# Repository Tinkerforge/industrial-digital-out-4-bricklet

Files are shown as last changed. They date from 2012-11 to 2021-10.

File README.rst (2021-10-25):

Industrial Digital Out 4 Bricklet
=================================

This repository contains the firmware source code and the hardware design
files. The documentation generator configs can be found at
https://github.com/Tinkerforge/generators

Repository Content
------------------

software/:
 * examples/: Examples for all supported languages
 * build/: Compiled files
 * src/: Source code of firmware
 * Makefile: Makefile to build project

hardware/:
 * Contains KiCad project files and additionally schematics as PDF

datasheets/:
 * Contains datasheets for sensors and complex ICs that are used

Hardware
--------

The hardware is designed with the open source EDA Suite KiCad
(http://www.kicad.org). Before you are able to open the files,
you have to install the Tinkerforge kicad-libraries
(https://github.com/Tinkerforge/kicad-libraries). You can either clone
them directly in hardware/ or clone them in a separate folder and
symlink them into hardware/
(ln -s kicad_path/kicad-libraries project_path/hardware). After that you
can open the .pro file in hardware/ with KiCad and from there view and
modify the schematics and the PCB layout.

Software
--------

If you want to do your own Brick/Bricklet firmware development we highly
recommend that you use our build environment setup script and read the
tutorial (https://www.tinkerforge.com/en/doc/Tutorials/Tutorial_Build_Environment/Tutorial.html).

To compile the C code we recommend you to install the newest GNU Arm Embedded
Toolchain (https://launchpad.net/gcc-arm-embedded/+download).
You also need to install bricklib (https://github.com/Tinkerforge/bricklib)
and brickletlib (https://github.com/Tinkerforge/brickletlib).

You can either clone it directly in software/src/ or clone it in a
separate folder and symlink it into software/src/
(ln -s bricklib_path/bricklib project_path/software/src/ and
ln -s brickletlib_path/brickletlib project_path/software/src/).
Finally make sure to have CMake installed
(http://www.cmake.org/cmake/resources/software.html).

After that you can build the firmware by invoking make in software/.
The firmware (.bin) can then be found in software/build/ and uploaded
with brickv (click button "Flashing" on start screen).

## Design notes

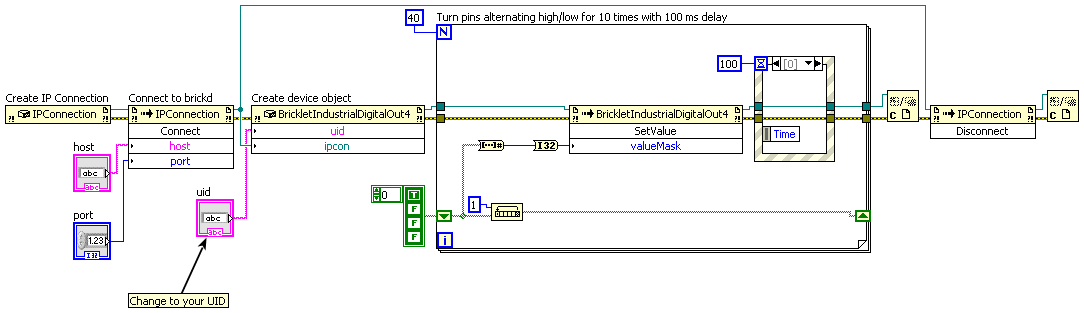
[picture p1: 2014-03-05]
software/examples/labview/Example Simple.vi.png

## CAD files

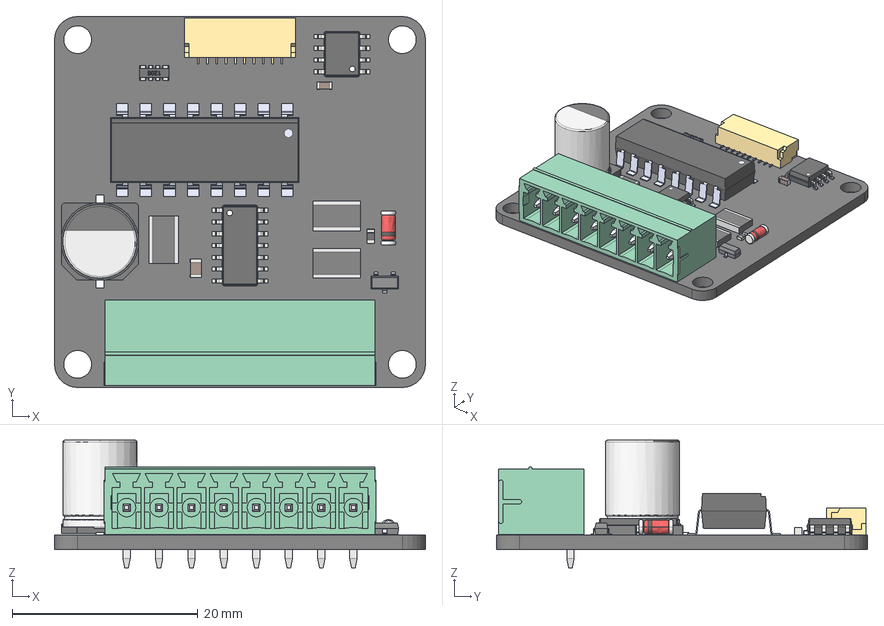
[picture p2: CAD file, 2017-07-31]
hardware/industrial-digital-out-4.step
40.0 x 40.0 x 13.8 mm

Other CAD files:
hardware/industrial-digital-out-4.FCStd

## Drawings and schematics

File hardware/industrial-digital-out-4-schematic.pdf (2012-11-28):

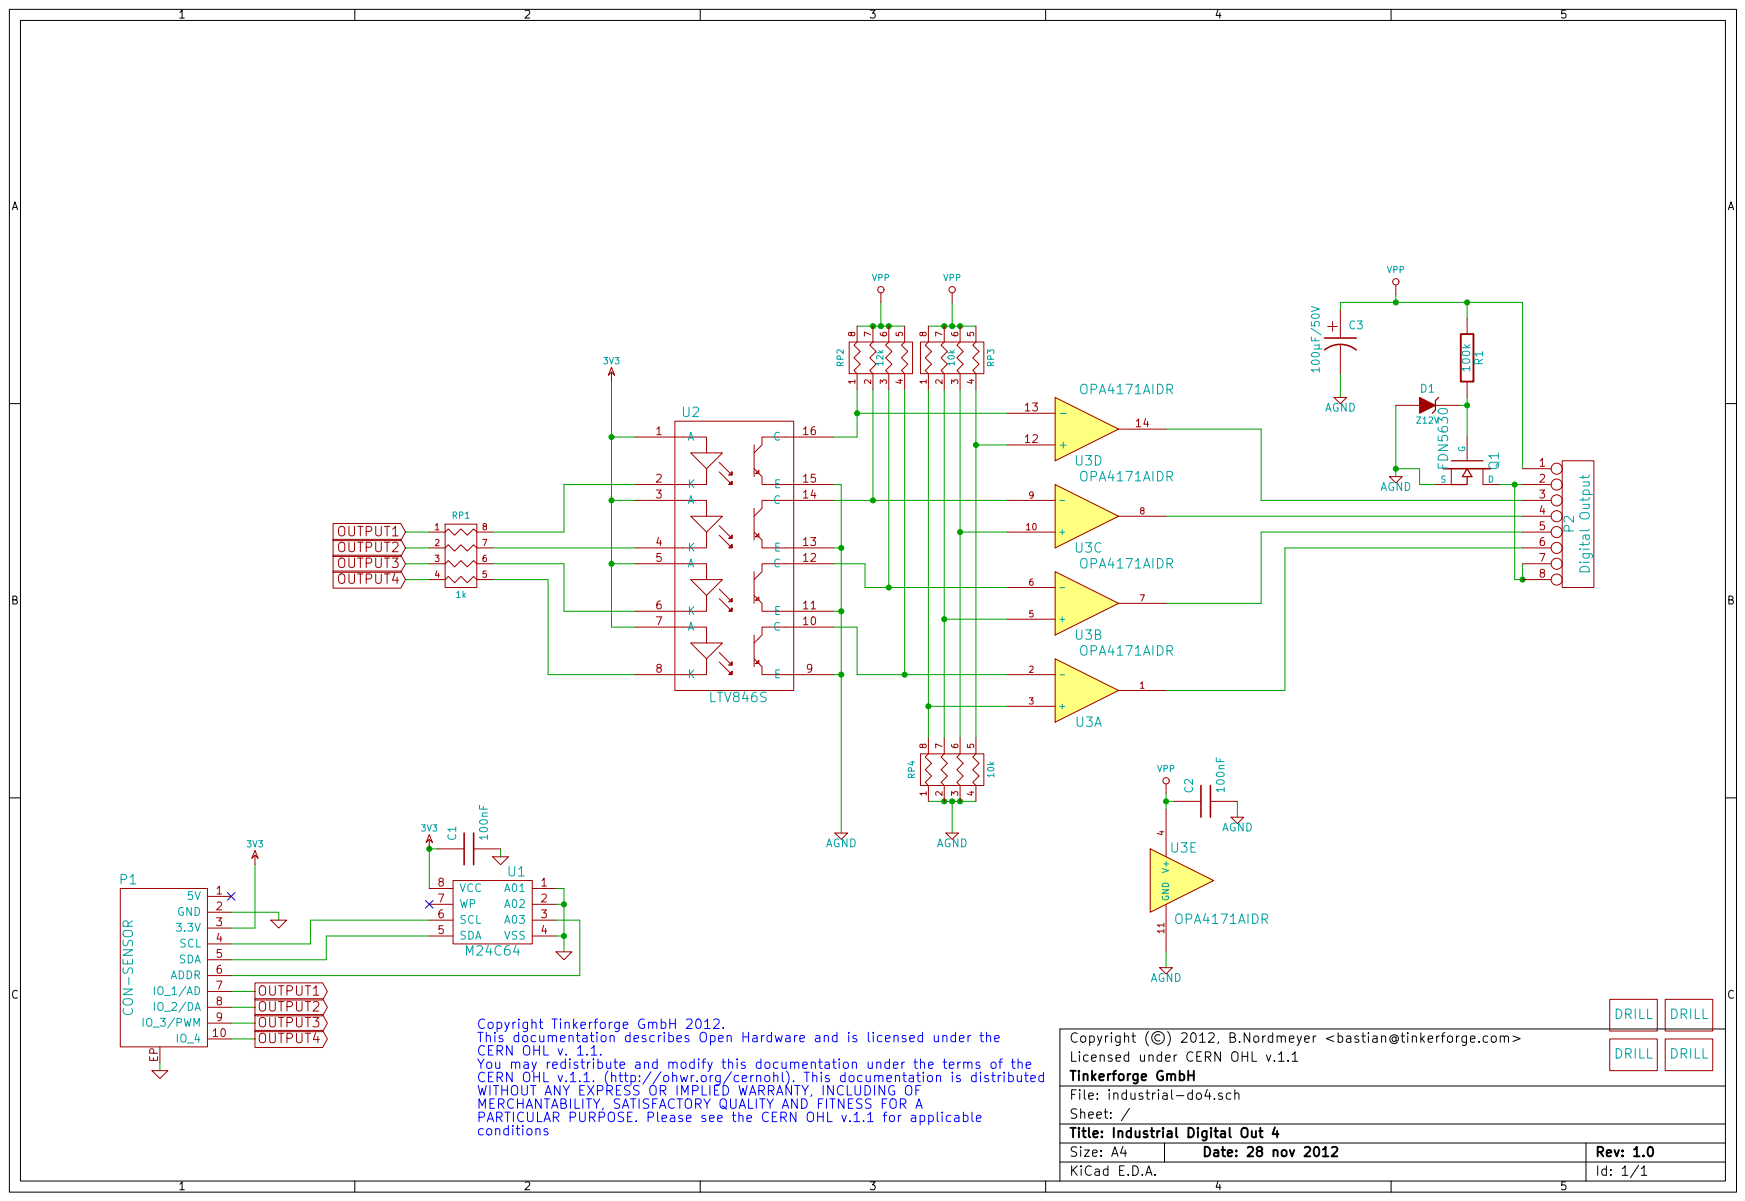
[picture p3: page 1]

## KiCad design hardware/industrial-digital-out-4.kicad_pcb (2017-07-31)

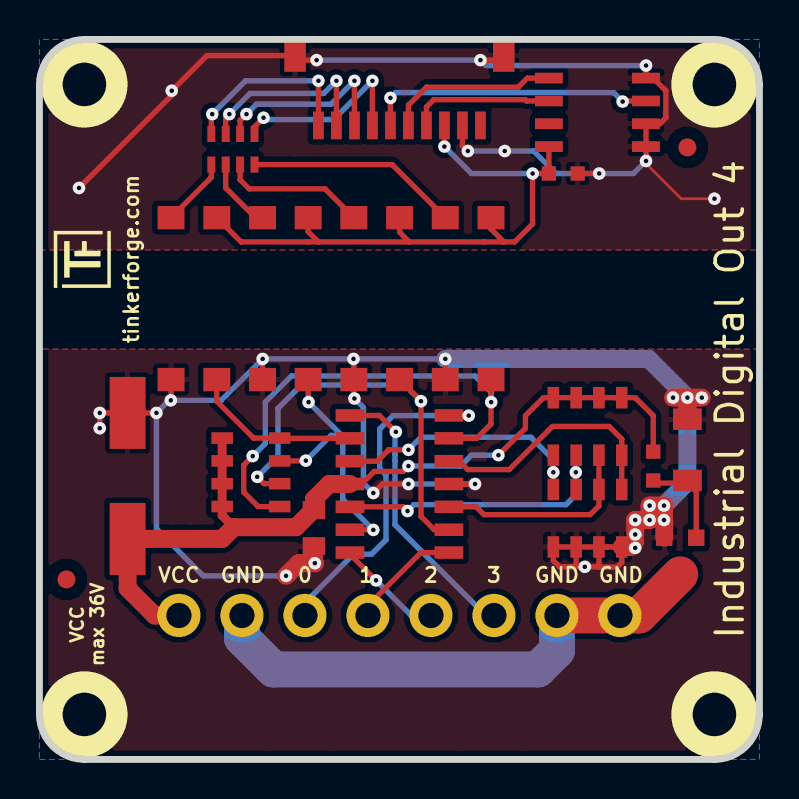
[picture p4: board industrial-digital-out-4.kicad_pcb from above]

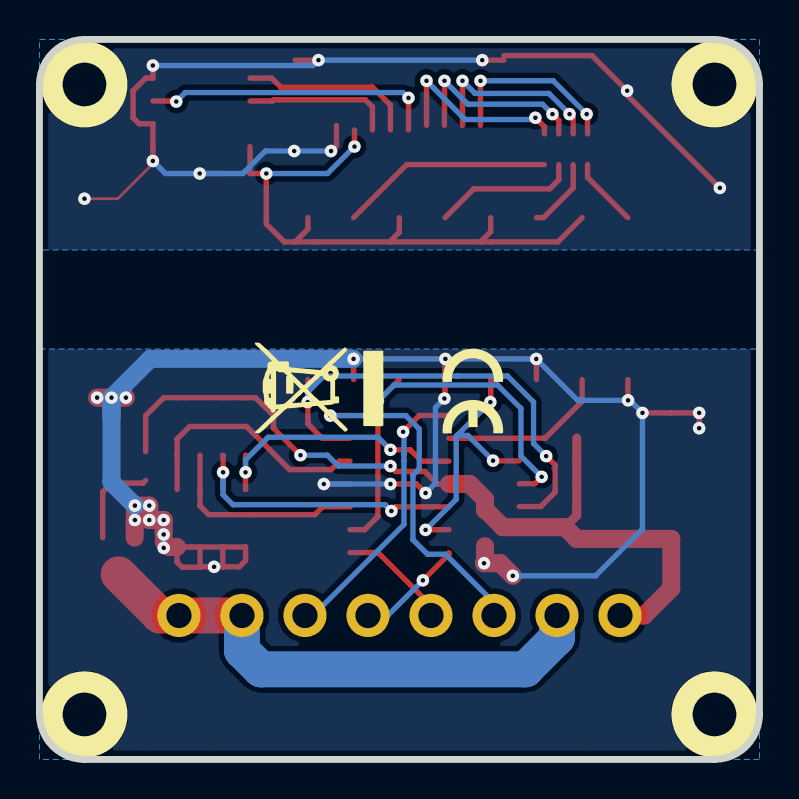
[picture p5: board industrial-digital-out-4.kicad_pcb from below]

Board: 2 copper layers, 40.0 x 40.0 mm, 23 parts (2 on the bottom side), 29 nets.

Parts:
C1: 100nF; C0603
C2: 100nF; C0805
C3: 68µF/50V; ELKO_83
D1: Z12V; MiniMelf
Fiducial_Mark: VAL**; Fiducial_Mark
Fiducial_Mark#2: VAL**; Fiducial_Mark
P1: CON-SENSOR
P2: Digital Output; OQ_8P
Q1: FDN5630; SOT23GDS
R1: 100k; R0603
RP1: 1k; 0603X4
RP2: 12k; 1206X4
RP3, RP4: 10k; 1206X4
U1: M24C64; SOIC8
U2: LTV846S; OPTO-SMD16
U3: OPA4171AIDR; SOP14
U4, U5, U6, U7: DRILL; DRILL_NP
VAL: WEEE_7mm
VAL#2: CE_5mm

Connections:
3V3: C1.1, P1.3, U1.8, U2.1, U2.3, U2.5, U2.7
AGND: C2.2, C3.2, D1.1, Q1.S, RP4.1, RP4.2, RP4.3, RP4.4, U2.9, U2.11, U2.13, U2.15, U3.11
GND: C1.2, P1.2, P1.EP, U1.1, U1.2, U1.4
unnamed: D1.2, Q1.G, R1.2
unnamed: P1.4, U1.6
unnamed: P1.5, U1.5
unnamed: P1.6, U1.3
unnamed: P2.2, P2.7, P2.8, Q1.D
unnamed: P2.3, U3.14
unnamed: P2.4, U3.8
unnamed: P2.5, U3.7
unnamed: P2.6, U3.1
unnamed: RP1.5, U2.8
unnamed: RP1.6, U2.6
unnamed: RP1.7, U2.4
unnamed: RP1.8, U2.2
unnamed: RP2.1, U2.16, U3.13
unnamed: RP2.2, U2.14, U3.9
unnamed: RP2.3, U2.12, U3.6
unnamed: RP2.4, U2.10, U3.2
unnamed: RP3.1, RP4.8, U3.3
unnamed: RP3.2, RP4.7, U3.5
unnamed: RP3.3, RP4.6, U3.10
unnamed: RP3.4, RP4.5, U3.12
OUTPUT1: P1.7, RP1.1
OUTPUT2: P1.8, RP1.2
OUTPUT3: P1.9, RP1.3
OUTPUT4: P1.10, RP1.4
VPP: C2.1, C3.1, P2.1, R1.1, RP2.5, RP2.6, RP2.7, RP2.8, RP3.5, RP3.6, RP3.7, RP3.8, U3.4

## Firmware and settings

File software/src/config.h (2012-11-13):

/* industrial-digital-out-4-bricklet
 * Copyright (C) 2012 Olaf Lüke <olaf@tinkerforge.com>
 *
 * config.h: Industrial Digital Out 4 Bricklet specific configuration
 *
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
 * You should have received a copy of the GNU Lesser General Public
 * License along with this library; if not, write to the
 * Free Software Foundation, Inc., 59 Temple Place - Suite 330,
 * Boston, MA 02111-1307, USA.
 */

#ifndef CONFIG_H
#define CONFIG_H

#include <stdint.h>
#include <stdbool.h>

#include "bricklib/drivers/board/sam3s/SAM3S.h"
#include "bricklib/drivers/pio/pio.h"
#include "brickletlib/bricklet_entry.h"

#include "digital_out_4.h"

#define BRICKLET_FIRMWARE_VERSION_MAJOR 2
#define BRICKLET_FIRMWARE_VERSION_MINOR 0
#define BRICKLET_FIRMWARE_VERSION_REVISION 0

#define BRICKLET_HARDWARE_VERSION_MAJOR 1
#define BRICKLET_HARDWARE_VERSION_MINOR 0
#define BRICKLET_HARDWARE_VERSION_REVISION 0

#define BRICKLET_DEVICE_IDENTIFIER 224

#define INVOCATION_IN_BRICKLET_CODE
#define PIN0 (BS->pin1_ad)
#define PIN1 (BS->pin2_da)
#define PIN2 (BS->pin3_pwm)
#define PIN3 (BS->pin4_io)

#define NUM_PINS 16

#define MAGIC_NUMBER_INDUSTRIAL_DIGITAL_OUT_4_1 951769416L
#define MAGIC_NUMBER_INDUSTRIAL_DIGITAL_OUT_4_2 3675893133L

typedef struct {
	Pin *pins[NUM_PINS];
	uint32_t time[NUM_PINS];
	uint32_t time_remaining[NUM_PINS];
	uint16_t monoflop_callback_mask;
	char group[4];
	uint32_t counter;
	uint32_t magic_number1;
	uint32_t magic_number2;
} BrickContext;

#endif

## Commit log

2012-11-28 Add Industrial Digital Out 4 hardware files
    [industrial-do4.brd, industrial-do4.sch]
2014-04-02 perl: Unify print style
2015-03-26 update to latest hardware files
    [industrial-do4.brd]
2015-08-07 Use full device class name in Python example
2016-05-18 c: Add missing device destroy call
2016-09-02 adapt capacitor value to 68µF
    [industrial-do4.brd, industrial-do4.sch]
2017-07-28 Fix broken symbols and broken orientation
    [industrial-do4.sch]
2017-07-28 Add 3d information (final)
    [industrial-do4.sch]
2017-07-28 add missing pcb file
    [industrial-do4.kicad_pcb]
2017-07-28 Add 3d information (tbc)
    [industrial-do4.kicad_pcb]
2017-07-31 Add 3d model (*.step & *.FCStd)
    [industrial-do4.step, industrial_do4.FCStd]
2017-07-31 Rename *.FCStd file
    [industrial-do4.FCStd]
2018-02-20 Cleanup KiCad libraries config
    Ensure LibDir=kicad-libraries and LibName1=tinkerforge.
    Remove special library.
2018-05-11 Rename files
    [industrial-digital-out-4-bricklet.FCStd, industrial-digital-out-4-bricklet.kicad_pcb, industrial-digital-out-4-bricklet.sch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]
2018-05-11 Rename files correctly
    [industrial-digital-out-4.FCStd, industrial-digital-out-4.kicad_pcb, industrial-digital-out-4.sch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]
2021-10-25 Update KiCad link
    https://www.kicad.org/blog/2021/10/Avoid-links-to-former-kicad-domain/

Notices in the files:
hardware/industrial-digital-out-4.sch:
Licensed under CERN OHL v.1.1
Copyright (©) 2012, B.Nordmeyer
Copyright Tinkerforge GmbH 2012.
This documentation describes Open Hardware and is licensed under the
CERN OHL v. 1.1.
